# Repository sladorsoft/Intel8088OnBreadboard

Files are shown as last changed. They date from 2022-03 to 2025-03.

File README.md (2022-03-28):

# 16-bit Intel x86 breadboard computer tutorial

This repository holds all the source code and other resources used in my tutorial series on **[YouTube](https://www.youtube.com/c/SladorSoft)**.

You can find the source code used in each video in the **src** directory and a schematic of each contraption in **schematics**.
They have been created with [KiCad](https://www.kicad.org/). Please note, that I have been using **version 6**, so the schematics may not be down-compatible with the older versions of KiCad.
There are also PDF versions of each of the schematics included.

For more details visit my website **[slador.uk](https://slador.uk/)**

If you find it interesting, please consider **[subscribing](https://www.youtube.com/c/SladorSoft)**.

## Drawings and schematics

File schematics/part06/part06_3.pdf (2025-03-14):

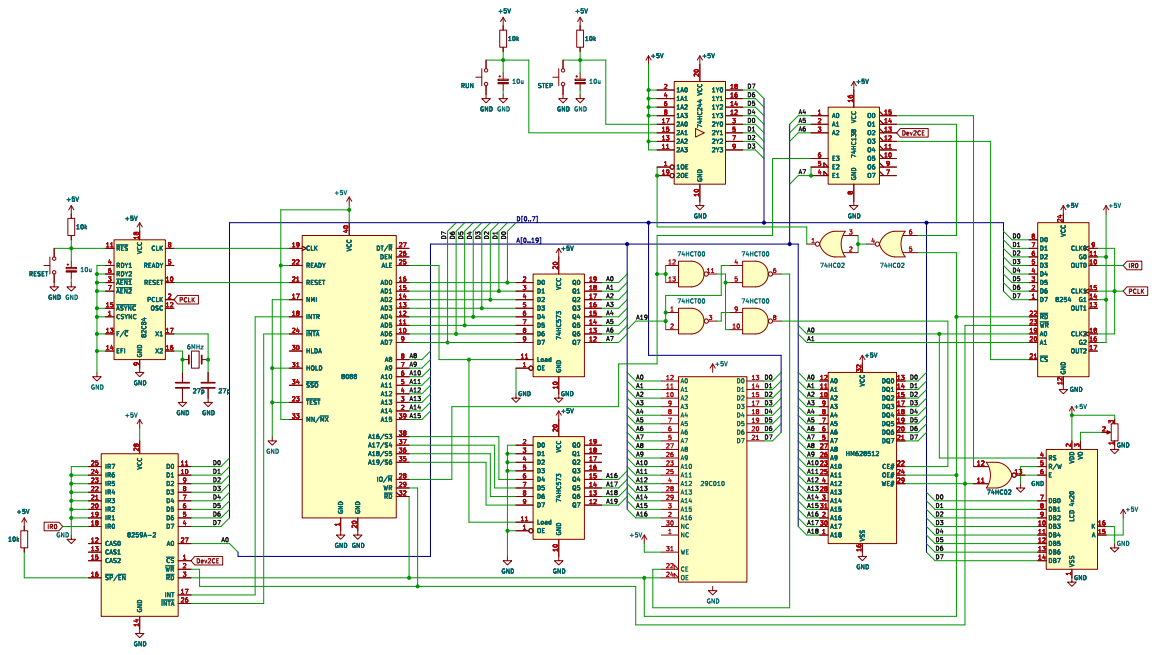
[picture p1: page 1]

IR0 Dev2CE Dev2CE
8088 CLK 19 READY 22 RESET 21 NMI 17

9 CLK 8 READY 5 RESET 10 PCLK 2 OSC 12 X1 17 X2 16 82C84 +5V

9 CLK 8 READY 5 RESET 10 PCLK 2 OSC 12 X1 17 X2 16 +5VGND

CLK 19 READY 22 RESET 21 NMI 17

+5V GND
INT 17 ~{INTA}26 VCC 28 GND 14

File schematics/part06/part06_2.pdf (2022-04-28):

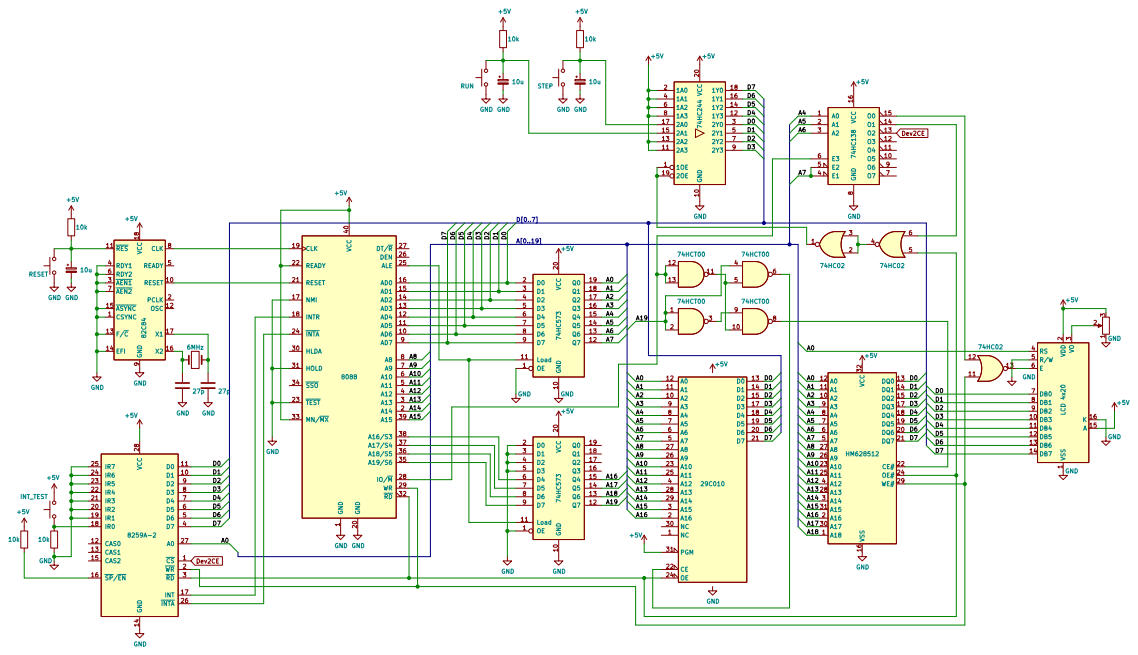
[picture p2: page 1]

+5V GND GND GND GND

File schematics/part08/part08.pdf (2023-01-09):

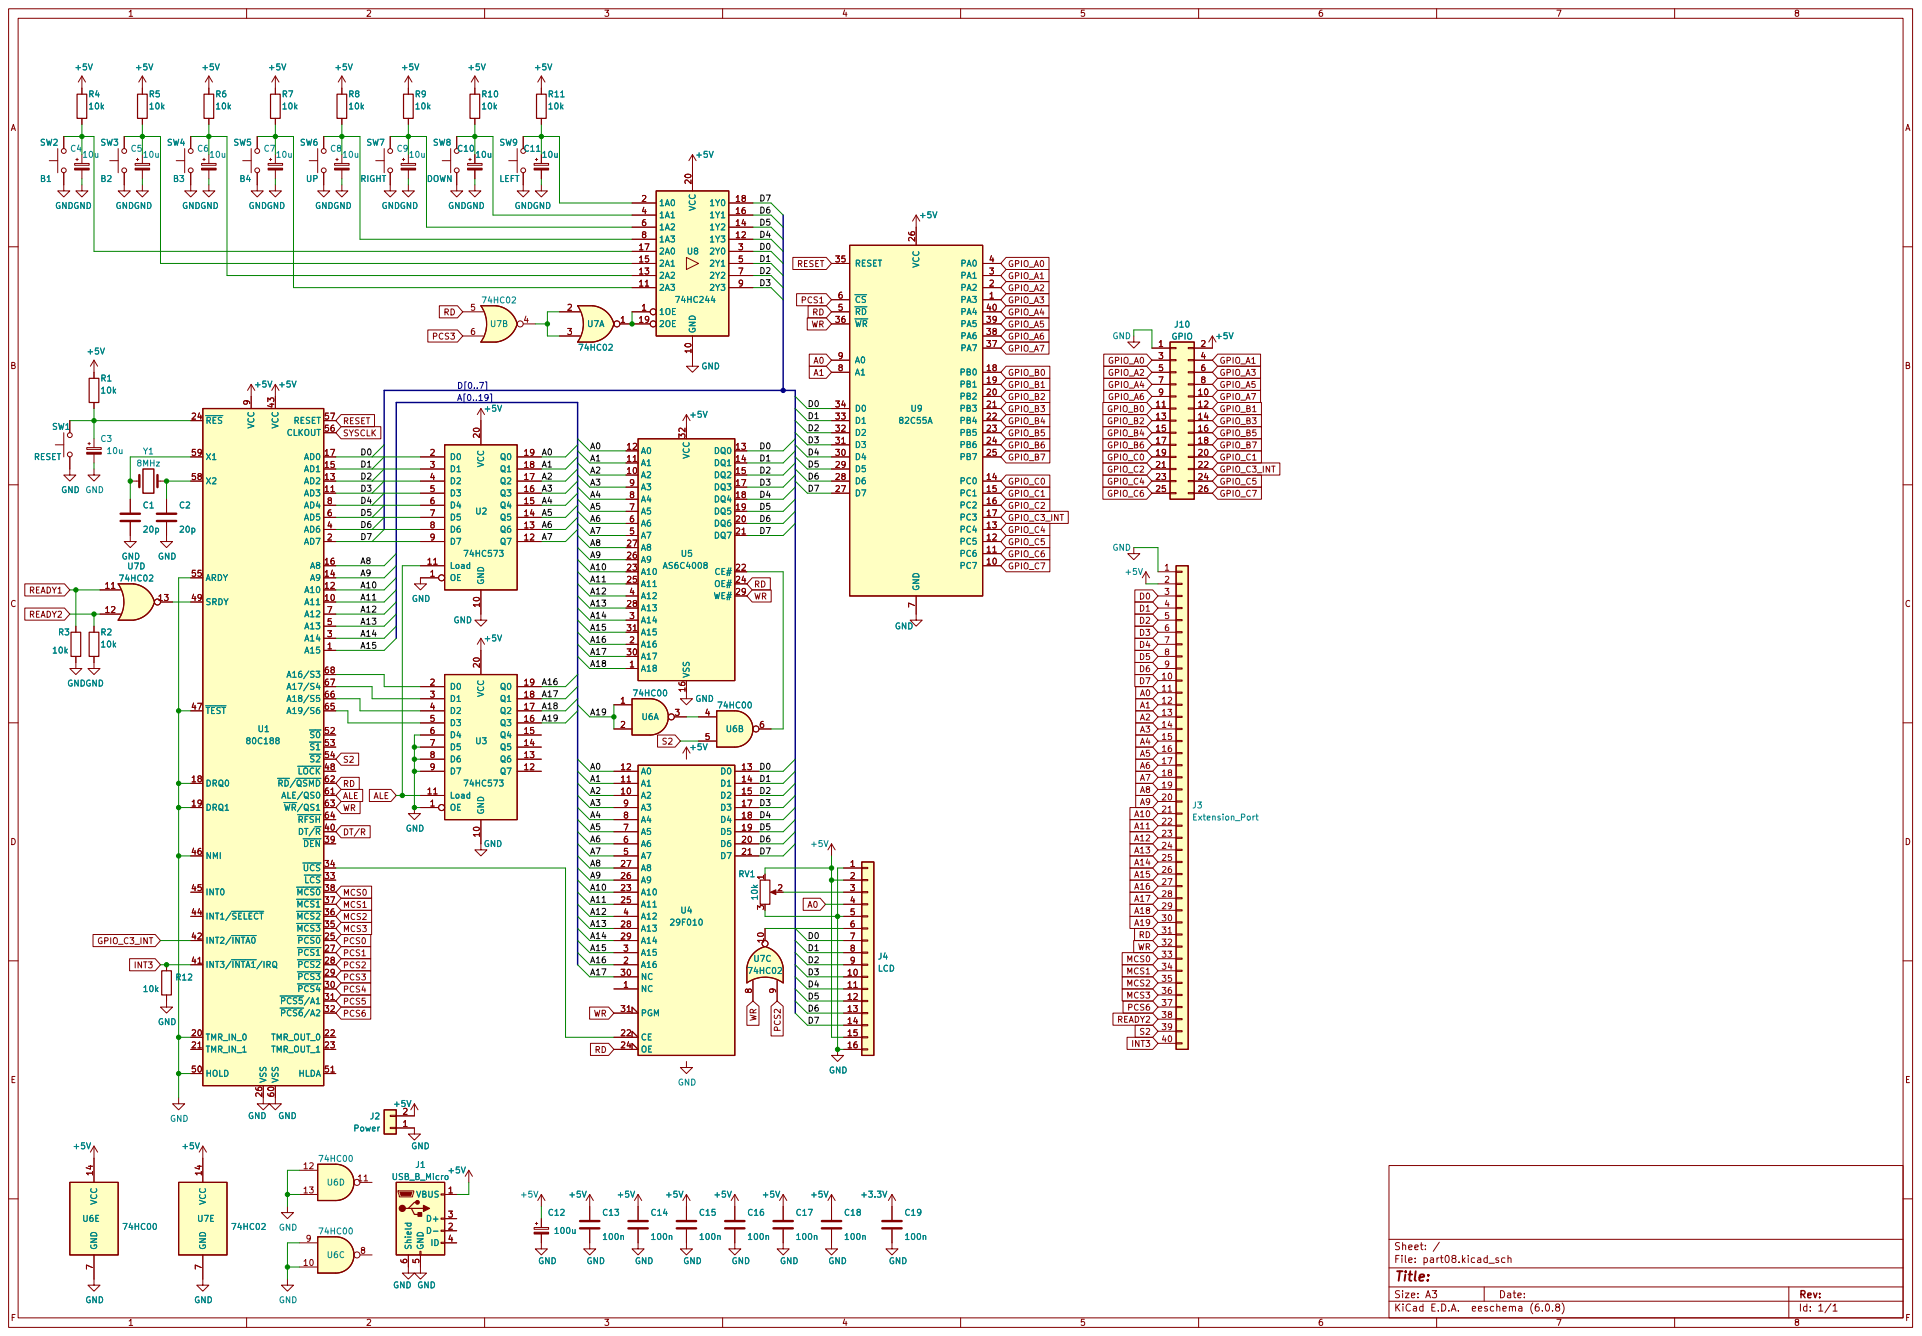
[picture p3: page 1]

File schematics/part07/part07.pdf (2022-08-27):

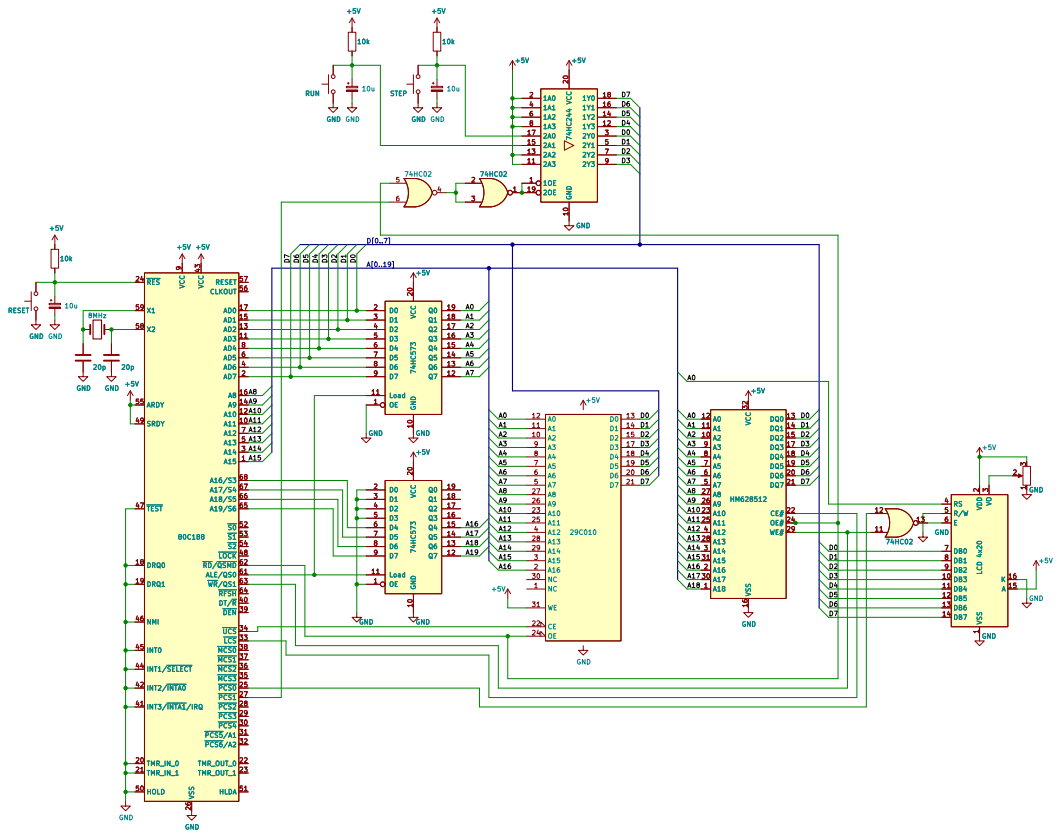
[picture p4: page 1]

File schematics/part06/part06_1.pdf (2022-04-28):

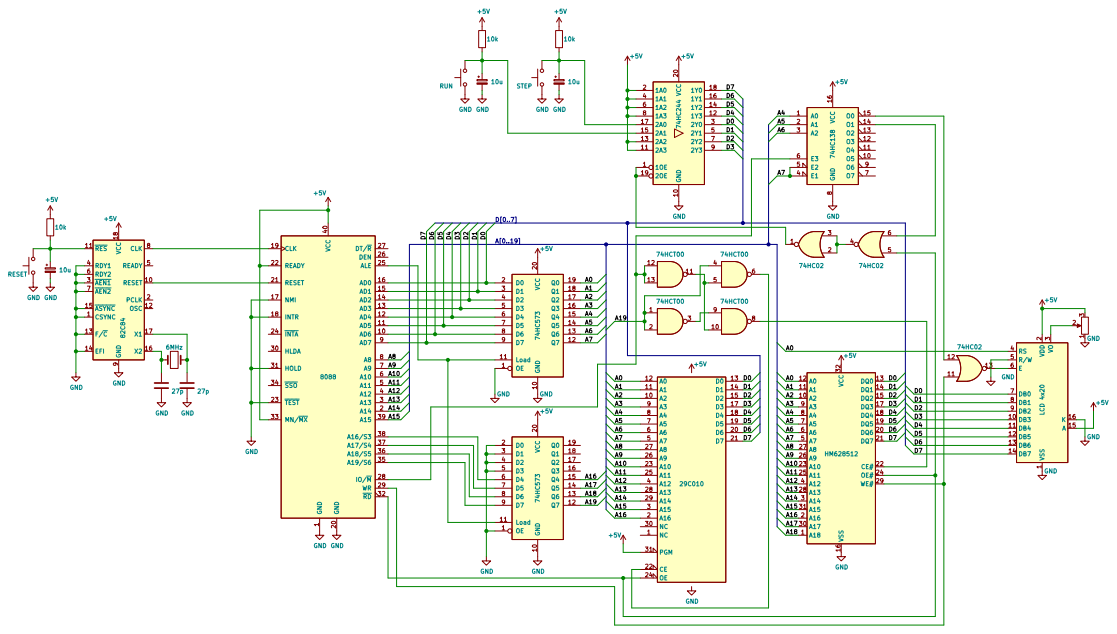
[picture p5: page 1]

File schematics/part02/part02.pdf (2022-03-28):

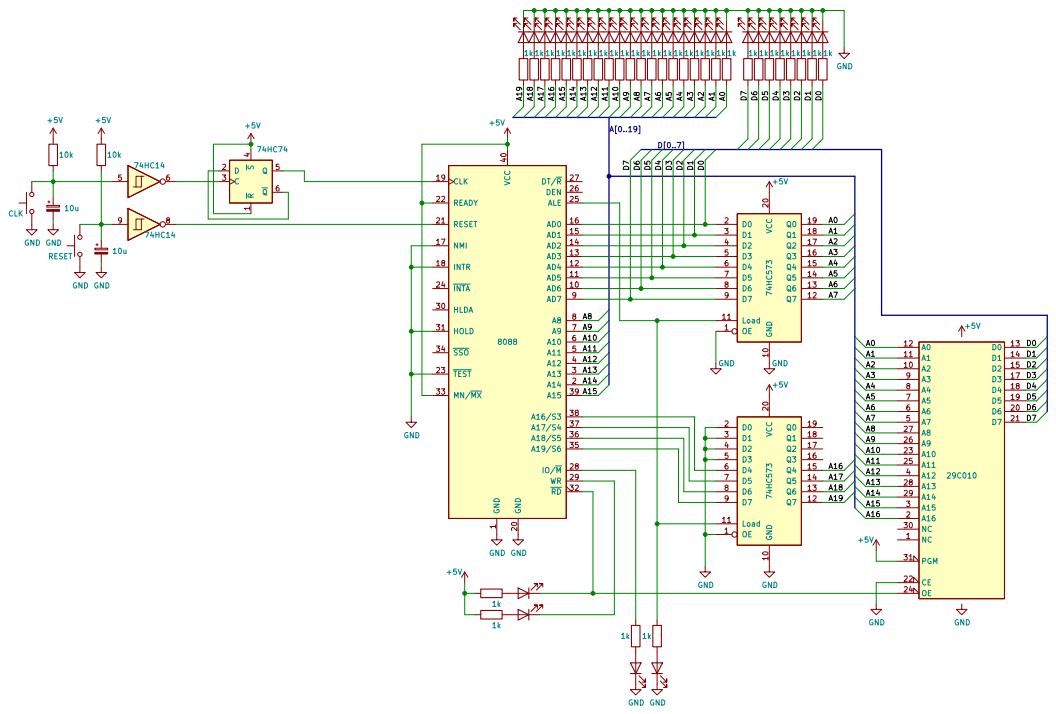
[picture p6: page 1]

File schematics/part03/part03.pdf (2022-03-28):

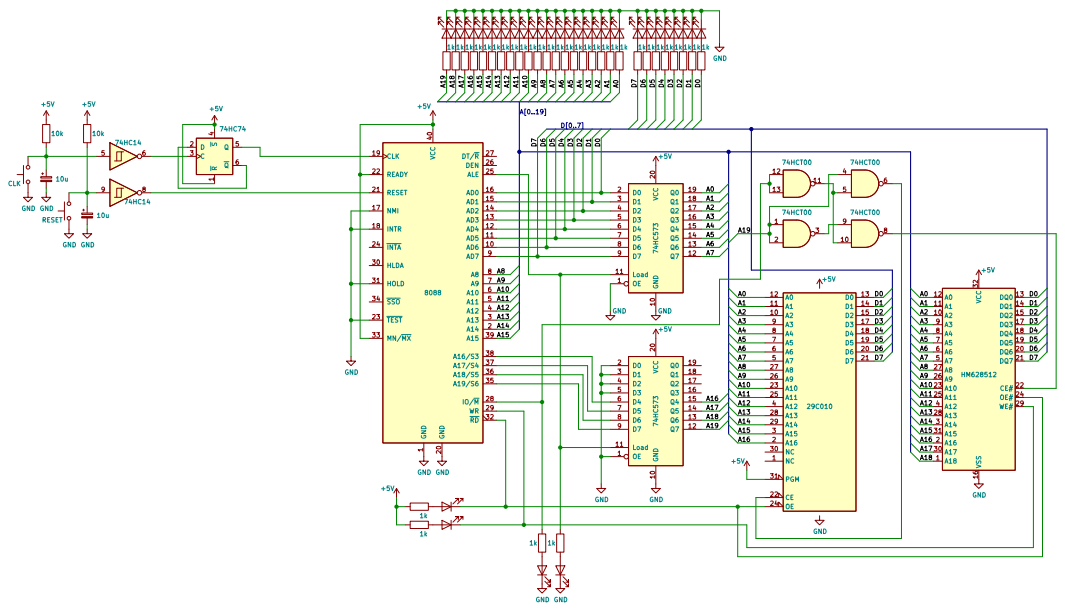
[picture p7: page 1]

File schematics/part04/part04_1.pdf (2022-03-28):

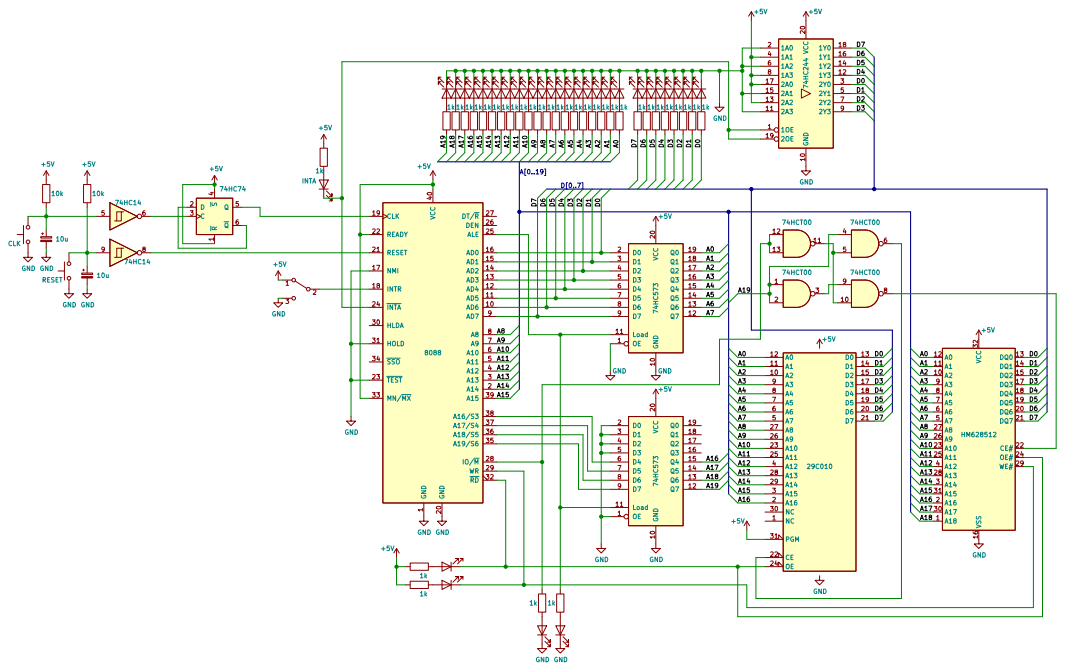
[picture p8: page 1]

6 | | 14
8 | | 12
17 | | 3
15 | | 5
13 | | 7

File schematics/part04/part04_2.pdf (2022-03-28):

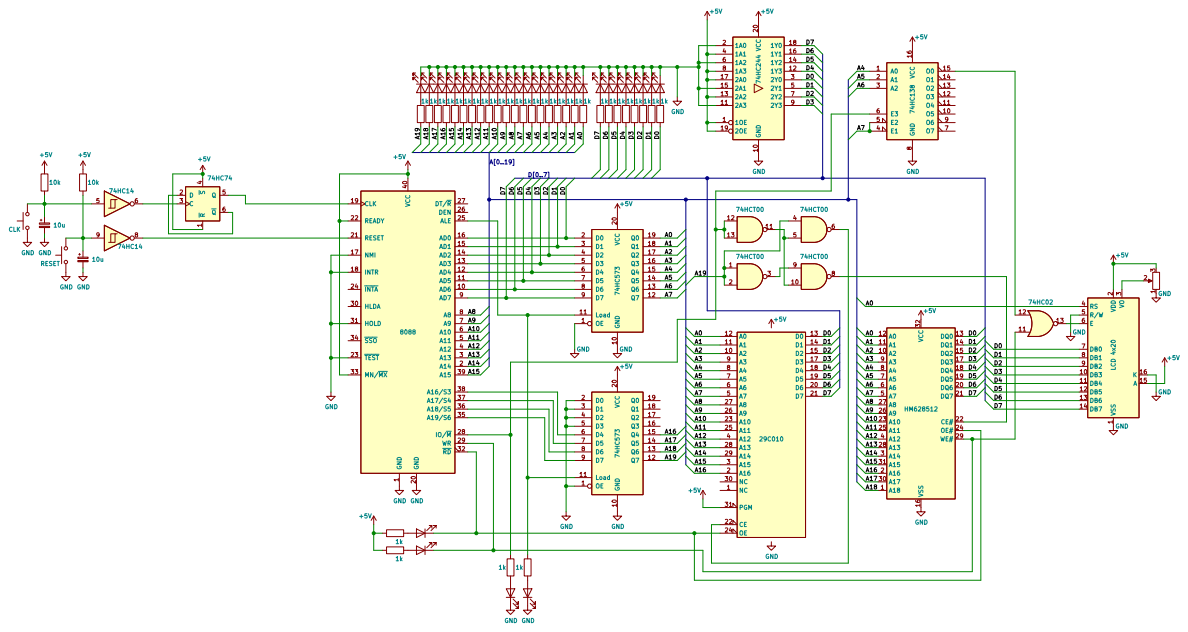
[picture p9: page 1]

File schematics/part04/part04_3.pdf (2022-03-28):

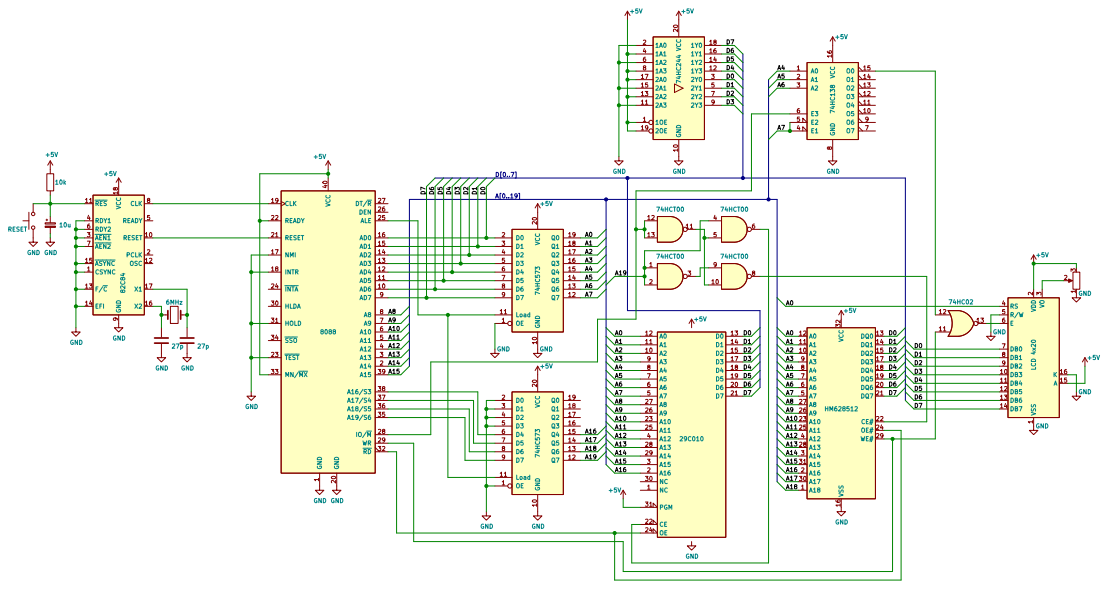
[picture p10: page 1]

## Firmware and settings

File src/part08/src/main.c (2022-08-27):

#include <stdint.h>
#include <stdbool.h>
#include <stdlib.h>
#include <string.h>

#include "utils.h"
#include "text_lcd.h"
#include "system.h"


void lcd_init()
{
    delay(2000);
    text_lcd_function_set();
    delay(400);
    text_lcd_function_set();
    delay(10);
    text_lcd_function_set();
    delay(4);
    text_lcd_function_set();
    delay(4);
    text_lcd_display_ctrl(false, false, false);
    delay(4);
    text_lcd_clear_display();
    delay(4);
    text_lcd_return_home();
    delay(150);
    text_lcd_entry_mode_set(true, false);
    delay(4);
    text_lcd_display_ctrl(true, false, false);
    delay(4);
}

void main()
{
    uint32_t lastSysTick = 0;
    while (1)
    {
        char buff[8];
        utoa((uint16_t)(lastSysTick / 100), buff, 10);
        text_lcd_send_text_at(9, 1, buff);

        while (1)
        {
            uint32_t currSysTick = get_sys_ticks();
            if ((currSysTick - lastSysTick) >= 100)
            {
                lastSysTick = currSysTick;
                break;
            }
        }
    }
}

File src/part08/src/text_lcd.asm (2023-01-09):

        CPU 186
        BITS 16

%include "system_def.inc"

        SECTION .text

        GLOBAL text_lcd_clear_display
        GLOBAL text_lcd_return_home
        GLOBAL text_lcd_entry_mode_set
        GLOBAL text_lcd_display_ctrl
        GLOBAL text_lcd_function_set
        GLOBAL text_lcd_set_char_gen_addr
        GLOBAL text_lcd_set_xy
        GLOBAL text_lcd_send_char
        GLOBAL text_lcd_send_char_at
        GLOBAL text_lcd_send_text
        GLOBAL text_lcd_send_text_at

        EXTERN delay

TEXT_LCD_CHARS_PER_LINE EQU     20
TEXT_LCD_LINES          EQU     4
TEXT_LCD_LINE_1_ADDR    EQU     0x40

SEND_TEXT_DELAY_VALUE   EQU     25


%ifdef TEXT_LCD_USING_8255

%macro TEXT_LCD_WRITE_CMD 0
        xchg ah, al
        mov al, 0b00011111
        out GPIO_PORTC_REG, al

        xchg ah, al
        out GPIO_PORTA_REG, al

        mov al, 0b10011111
        out GPIO_PORTC_REG, al

        mov al, 0b00011111
        out GPIO_PORTC_REG, al
%endmacro

%macro TEXT_LCD_WRITE_CMD 1
        mov al, 0b00011111
        out GPIO_PORTC_REG, al

        mov al, %1
        out GPIO_PORTA_REG, al

        mov al, 0b10011111
        out GPIO_PORTC_REG, al

        mov al, 0b00011111
        out GPIO_PORTC_REG, al
%endmacro

%macro TEXT_LCD_WRITE_DATA 0
        xchg ah, al
        mov al, 0b00111111
        out GPIO_PORTC_REG, al

        xchg ah, al
        out GPIO_PORTA_REG, al

        mov al, 0b10111111
        out GPIO_PORTC_REG, al

        mov al, 0b00111111
        out GPIO_PORTC_REG, al
%endmacro


%else


%macro TEXT_LCD_WRITE_CMD 0
        mov dx, TEXT_LCD_CMD
        out dx, al
%endmacro

%macro TEXT_LCD_WRITE_CMD 1
        mov al, %1
        mov dx, TEXT_LCD_CMD
        out dx, al
%endmacro

%macro TEXT_LCD_WRITE_DATA 0
        mov dx, TEXT_LCD_DATA
        out dx, al
%endmacro

%endif



;--------------------------------------
; void text_lcd_clear_display()
;--------------------------------------
text_lcd_clear_display:
        TEXT_LCD_WRITE_CMD 0b00000001
        ret

;--------------------------------------
; void text_lcd_return_home()
;--------------------------------------
text_lcd_return_home:
        TEXT_LCD_WRITE_CMD 0b00000010
        ret

;--------------------------------------
; void text_lcd_entry_mode_set(bool increment, bool disp_shift)
;--------------------------------------
text_lcd_entry_mode_set:
        mov bx, sp
        mov al, 0b00000100
        mov ah, [bx + 2]
        test ah, ah
        jz .1
        or al, 0b00000010
.1:
        mov ah, [bx + 4]
        test ah, ah
        jz .2
        or al, 0b00000001
.2:
        TEXT_LCD_WRITE_CMD
        ret

;--------------------------------------
; void text_lcd_display_ctrl(bool is_on, bool cursor_visible, bool cursor_blink)
;--------------------------------------
text_lcd_display_ctrl:
        mov bx, sp
        mov al, 0b00001000
        mov ah, [bx + 2]
        test ah, ah
        jz .1
        or al, 0b00000100
.1:
        mov ah, [bx + 4]
        test ah, ah
        jz .2
        or al, 0b00000010
.2:
        mov ah, [bx + 6]
        test ah, ah
        jz .3
        or al, 0b00000001
.3:
        TEXT_LCD_WRITE_CMD
        ret

;--------------------------------------
; void text_lcd_function_set()
;--------------------------------------
text_lcd_function_set:
        TEXT_LCD_WRITE_CMD 0b00111000
        ret

;--------------------------------------
; void text_lcd_set_char_gen_addr(uint8_t addr)
;--------------------------------------
text_lcd_set_char_gen_addr:
        mov bx, sp
        mov al, 0b01000000
        mov ah, [bx + 2]
        and ah, 0b00111111
        or al, ah
        TEXT_LCD_WRITE_CMD
        ret

;--------------------------------------
; void text_lcd_set_disp_addr(uint8_t addr)
;--------------------------------------
text_lcd_set_disp_addr:
        mov bx, sp
        mov al, 0b10000000
        mov ah, [bx + 2]
        and ah, 0b01111111
        or al, ah
        TEXT_LCD_WRITE_CMD
        ret

;--------------------------------------
; void text_lcd_set_xy(uint8_t x, uint8_t y)
;--------------------------------------
text_lcd_set_xy:
        push bp
        mov bp, sp

        xor dx, dx
        mov al, [bp + 6]
        test al, 0b00000001
        jz .1
        mov dl, TEXT_LCD_LINE_1_ADDR
.1:
        test al, 0b00000010
        jz .2
        add dl, TEXT_LCD_CHARS_PER_LINE
.2:
        mov al, [bp + 4]
        add dl, al
        push dx
        call text_lcd_set_disp_addr
        add sp, 2

        mov sp, bp
        pop bp
        ret

;--------------------------------------
; void text_lcd_send_char(char c)
;--------------------------------------
text_lcd_send_char:
        mov bx, sp
        mov al, [bx + 2]
        TEXT_LCD_WRITE_DATA
        ret

;--------------------------------------
; void text_lcd_send_char_at(uint8_t x, uint8_t y, char c)
;--------------------------------------
text_lcd_send_char_at:
        push bp
        mov bp, sp

        mov al, [bp + 6]
        push ax
        mov al, [bp + 4]
        push ax
        call text_lcd_set_xy
        add sp, 4

        mov al, [bp + 8]
        TEXT_LCD_WRITE_DATA

        mov sp, bp
        pop bp
        ret

;--------------------------------------
; void text_lcd_send_text(const char* str)
;--------------------------------------
text_lcd_send_text:
        push bp
        mov bp, sp

        push si
        mov si, [bp + 4]
        test si, si
        jz .2
.1:
        lodsb
        test al, al
        jz .2
        TEXT_LCD_WRITE_DATA
        mov ax, SEND_TEXT_DELAY_VALUE
        push ax
        call delay
        add sp, 2
        jmp .1
.2:
        pop si

        mov sp, bp
        pop bp
        ret

;--------------------------------------
; void text_lcd_send_text_at(uint8_t x, uint8_t y, const char* str)
;--------------------------------------
text_lcd_send_text_at:
        push bp
        mov bp, sp

        mov al, [bp + 6]
        push ax
        mov al, [bp + 4]
        push ax
        call text_lcd_set_xy
        add sp, 4

        mov ax, [bp + 8]
        push ax
        call text_lcd_send_text

        mov sp, bp
        pop bp
        ret

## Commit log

2022-03-15 Initial commit of all of the resources
    [part02.kicad_sch, part03.kicad_sch, part04_1.kicad_sch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]
2022-03-28 Added PDF versions of the schematics
2022-04-28 Added files for part 6
    [part06_1.kicad_sch, part06_2.kicad_sch, part06_3.kicad_sch]
2022-08-27 Added files for part 7
    [part07.kicad_sch]
2023-01-09 Added files for part 8
    [part06_3.kicad_sch, part08.kicad_sch]
2025-03-14 Fixed errors in schematics. Thanks Greg for spotting these.
    [part06_3.kicad_sch]
